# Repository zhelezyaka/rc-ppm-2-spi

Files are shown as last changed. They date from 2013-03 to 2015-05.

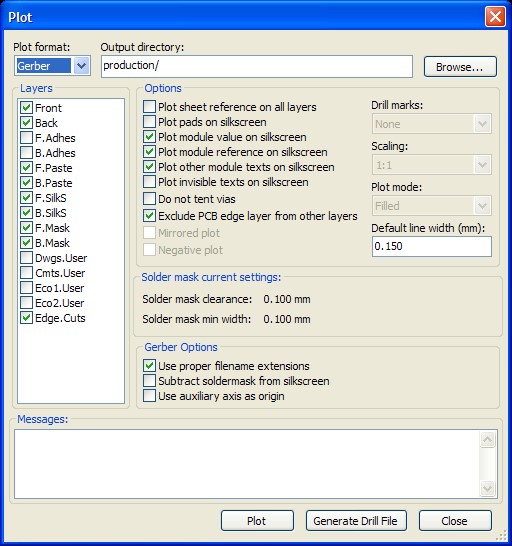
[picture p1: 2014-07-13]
pcb/production/kicad_gerber_settings.jpg

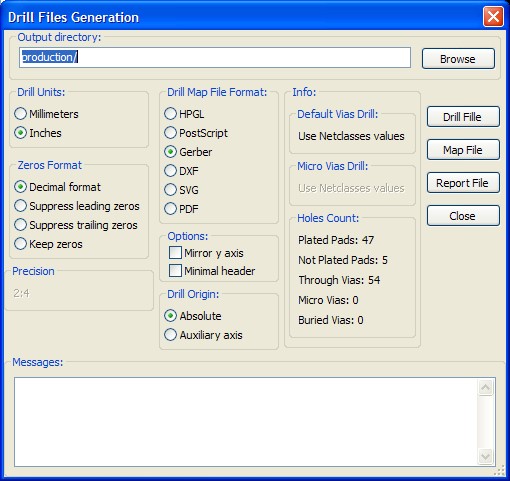
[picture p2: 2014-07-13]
pcb/production/kicad_drill_settings.jpg

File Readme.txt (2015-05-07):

# rc-ppm-2-spi
Automatically exported from:
http://code.google.com/p/rc-ppm-2-spi/

This project aims to provide you with a RC module that will allow you fly models featuring the A7105 transceiver chip 
using your favourite modular transmitter, instead of using the cheap efforts that are normally supplied.

http://rc-ppm-2-spi.googlecode.com/svn/wiki/images/overview/overview_03.jpg

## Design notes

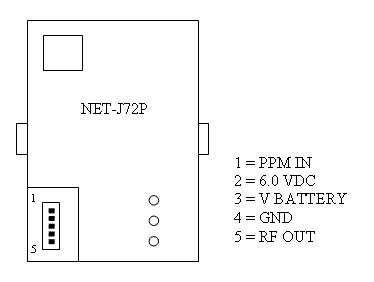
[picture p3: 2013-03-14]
datasheets/JR_module_pinout.gif

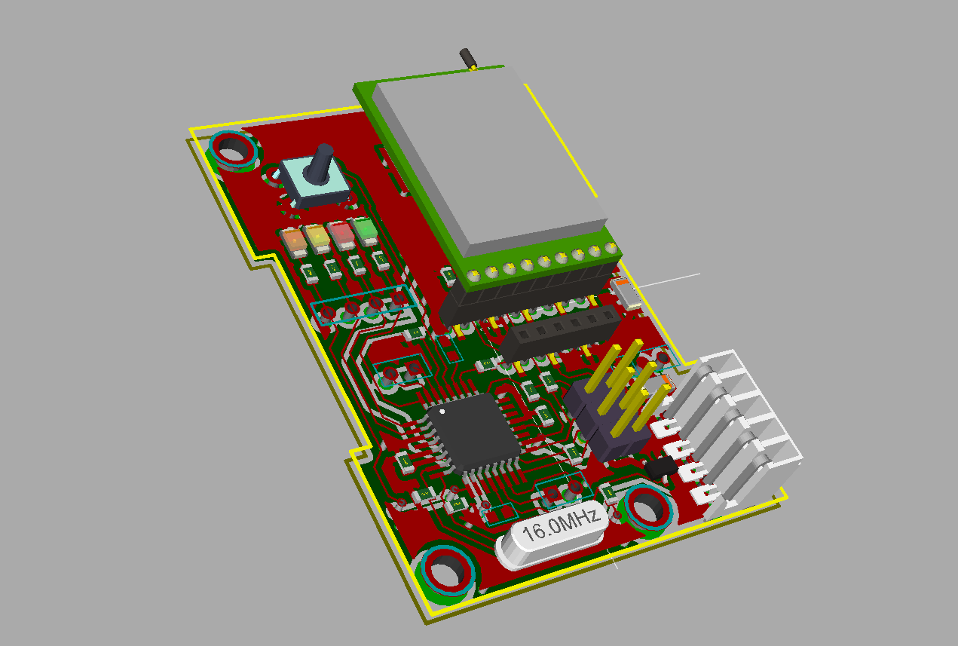
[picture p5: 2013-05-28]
pcb/ppm2spi_ali.png

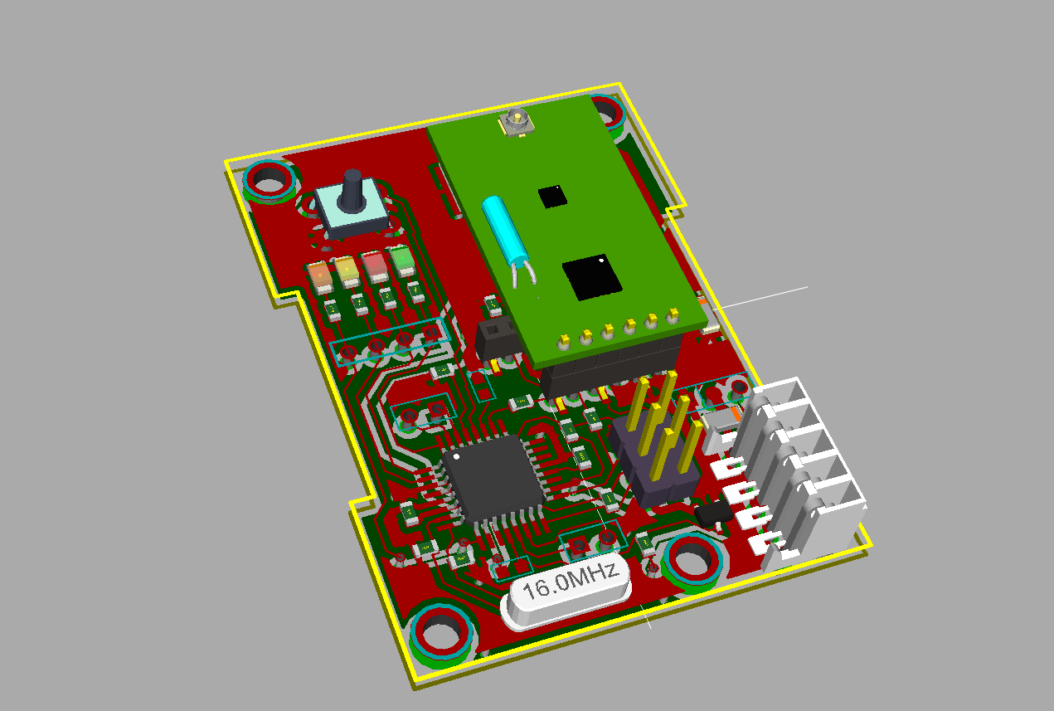
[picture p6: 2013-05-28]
pcb/ppm2spi_jp.png

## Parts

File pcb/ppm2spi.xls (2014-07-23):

Value | Qty | MOQ | Unit Cost | Qty Cost (Inc. VAT) | Designator | Footprint | Manufacturer | Manufactures Part No | Link | Comment | More Comments
18pF | 2 | 100 | £0.006 | £0.72 | C6 C7 | 0603 | Multicomp | MCCA000195 | http://uk.farnell.com/multicomp/mcca000195/cap-ceramic-18pf-50v-c0g-np0-0603/dp/1759056
100nF | 5 | 10 | £0.006 | £0.07 | C1 C4 C5 C9 C10 | 0603 | Multicomp | MC0603B104K250CT | http://uk.farnell.com/multicomp/mc0603b104k250ct/cap-mlcc-x7r-100nf-25v-0603/dp/1759037
10uf 6.3v | 1 | 5 | £0.120 | £0.72 | C8 | 1206 | Vishay Sprague | 293D106X96R3A2TE3 | http://uk.farnell.com/vishay-sprague/293d106x96r3a2te3/capacitor-tantalum-6-3v-10uf/dp/1754143
10uf 16v | 2 | 5 | £0.136 | £0.82 | C2 C3 | 1206 | Kemet | T491A106K016AT | http://uk.farnell.com/kemet/t491a106k016at/capacitor-tant-10uf-16v-10-1206/dp/1457414
Green LED | 1 | 5 | £0.130 | £0.78 | D1 | 0805 | Kingbright | KPHCM-2012CGCK | http://uk.farnell.com/jsp/search/productdetail.jsp?sku=1686075&CMP=i-7395-00001000
Red LED | 1 | 5 | £0.120 | £0.72 | D2 | 0805 | Kingbright | KPHCM-2012SURCK | http://uk.farnell.com/jsp/search/productdetail.jsp?sku=1686067&CMP=i-7395-00001000
Yellow LED | 1 | 5 | £0.120 | £0.72 | D3 | 0805 | Kingbright | KPHCM-2012SYCK | http://uk.farnell.com/jsp/search/productdetail.jsp?sku=1686073&CMP=i-7395-00001000
Orange LED | 1 | 5 | £0.120 | £0.72 | D4 | 0805 | Kingbright | KPHCM-2012SECK | http://uk.farnell.com/jsp/search/productdetail.jsp?sku=1686068&CMP=i-7395-00001000
BAT54S | 1 | 5 | £0.044 | £0.26 | D5 | SOT23 | NXP | BAT54S | http://uk.farnell.com/nxp/bat54s/diode-schoty-dual-30v-0-2a-sot23/dp/1081194
ATMEGA328-AU | 1 | 1 | £2.630 | £3.16 | IC1 | TQFP32 | Atmel | ATMEGA328-AU | http://uk.farnell.com/jsp/search/productdetail.jsp?id=1972086&Ntt=ATMEGA328-A
Molex KK100 4455 5 way | 1 | 5 | £0.620 | £3.72 | P1 | 0.1"x5 | Molex | 38-00-1395 | http://uk.farnell.com/jsp/search/productdetail.jsp?SKU=9732349
0.1" pin header 3 way | 1 | 1 | £1.480 | £1.78 | K1 | 0.1"x3 | FCI | 77311-401-36LF | http://uk.farnell.com/fci/77311-401-36lf/header-pin-tin-36way-1row/dp/1097954 | Optional for alternative PPM input
0.1" pin header 2 way | 1 | NA | NA | NA | P5 | 0.1"x2 | As above | As above | As above | Optional for debugging - PB1 PB2
0.1" pin header 2 way | 1 | NA | NA | NA | P7 | 0.1"x2 | As above | As above | As above | Optional for debugging- Tx Rx
0.1" pin header 4 way | 1 | NA | NA | NA | P6 | 0.1"x4 | As above | As above | As above | Optional for debugging - LED signals
0.1" pin header 3x2 way | 1 | 1 | £2.310 | £2.77 | P3 | 0.1"x3x2 | Harwin | M20-9983646 | http://uk.farnell.com/harwin/m20-9983646/header-2row-36-36way/dp/1022244 | ISP Header
2mm pin socket 6 way | 1 | 1 | £2.170 | £2.60 | P2 | 2mmx6 | Samtec | SMM-110-02-S-S | http://uk.farnell.com/samtec/smm-110-02-s-s/receptacle-2mm-single-10way/dp/1668127 | Cut to length - For use with WL Toys module | Xbee trough hole headers are a cheaper alternative
2mm pin socket 9 way | 1 | NA | NA | NA | P4 | 2mmx9 | As above | As above | As above (http://uk.farnell.com/samtec/smm-109-01-s-s/socket-2-0mm-1x9way/dp/1804773) | Cut to length - For use with AliExpress A7105 500m module | Xbee through hole headers are a cheaper alternative
1K | 8 | 50 | £0.011 | £0.66 | R2 R3 R4 R7 R9 R10 R11 R12 | 0603 | Vishay Draloric | CRCW06031K00FKEA | http://uk.farnell.com/vishay-draloric/crcw06031k00fkea/resistor-0603-1kr-1-0-1w/dp/1469740
2K | 3 | 50 | £0.009 | £0.54 | R1 R5 R6 | 0603 | Panasonic | ERJ3GEYJ202V | http://uk.farnell.com/panasonic/erj3ekf2001v/resistor-2k-0-1w-1/dp/2059343
10K | 1 | 50 | £0.011 | £0.66 | R8 | 0603 | Vishay Draloric | CRCW060310K0FKEA | http://uk.farnell.com/vishay-draloric/crcw060310k0fkea/resistor-10k-0-1w-1-0603-smd/dp/1469748
SW_PUSH | 1 | 1 | £0.130 | £0.16 | SW1 | 6x6mm | Alps | SKHHANA010 | http://uk.farnell.com/alps/skhhana010/switch-tactile-6x6mm-vert-blk/dp/2056810
5v Regulator | 1 | 1 | £0.540 | £0.65 | U1 | SOT89 | Microchip | MCP1703AT-5002E/MB | http://uk.farnell.com/microchip/mcp1703at-5002e-mb/ldo-2-7-16vin-0-25a-5v-2-3sot89/dp/2218577 | Pin order: OUT GND IN
3.3v Regulator | 1 | 1 | £0.720 | £0.86 | U2 | DPAK2 | ST | KF33BDT-TR | http://uk.farnell.com/stmicroelectronics/kf33bdt-tr/ic-v-reg-ldo-3-3v-smd/dp/1467756 | Pin order: IN GND OUT
16Mhz Crystal | 1 | 1 | £0.270 | £0.32 | X1 | HC49 | Raltron | AS-16.000-18 | http://uk.farnell.com/raltron/as-16-000-18/crystal-16m-18pf-cl-hc49-4h/dp/1611761
A7105 RF module | 1 | 1 | £6.008 | £7.21 | Connects to P2 or P4 | NA | NA | NA | http://www.aliexpress.com/item/A7105-Wireless-RF-2-4GHz-Transceiver-Module-3-3V-NRF24L01-SI4432-10dBm-64mA-20mA/619869938.html | Either taken from original Tx or bought from AliExpress
Spektrum module case | 1 | 1 | £12.908 | £15.49 | NA | NA | Spektrum | SPM6817E | http://www.horizonhobby.co.uk/aeroonline/e6spektrum/e6_modules/e6_jr_module/e6_jr.html
Total Cost inc. VAT |  |  |  | £46.11

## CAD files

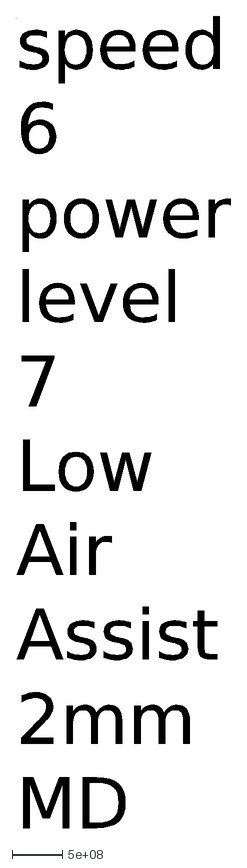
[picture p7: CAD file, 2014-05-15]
diymodulecase/diymodulecase.dxf
speed 6 power level 7 Low Air Assist 2mm MDF

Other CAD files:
diymodulecase/diymodulecase.dwg

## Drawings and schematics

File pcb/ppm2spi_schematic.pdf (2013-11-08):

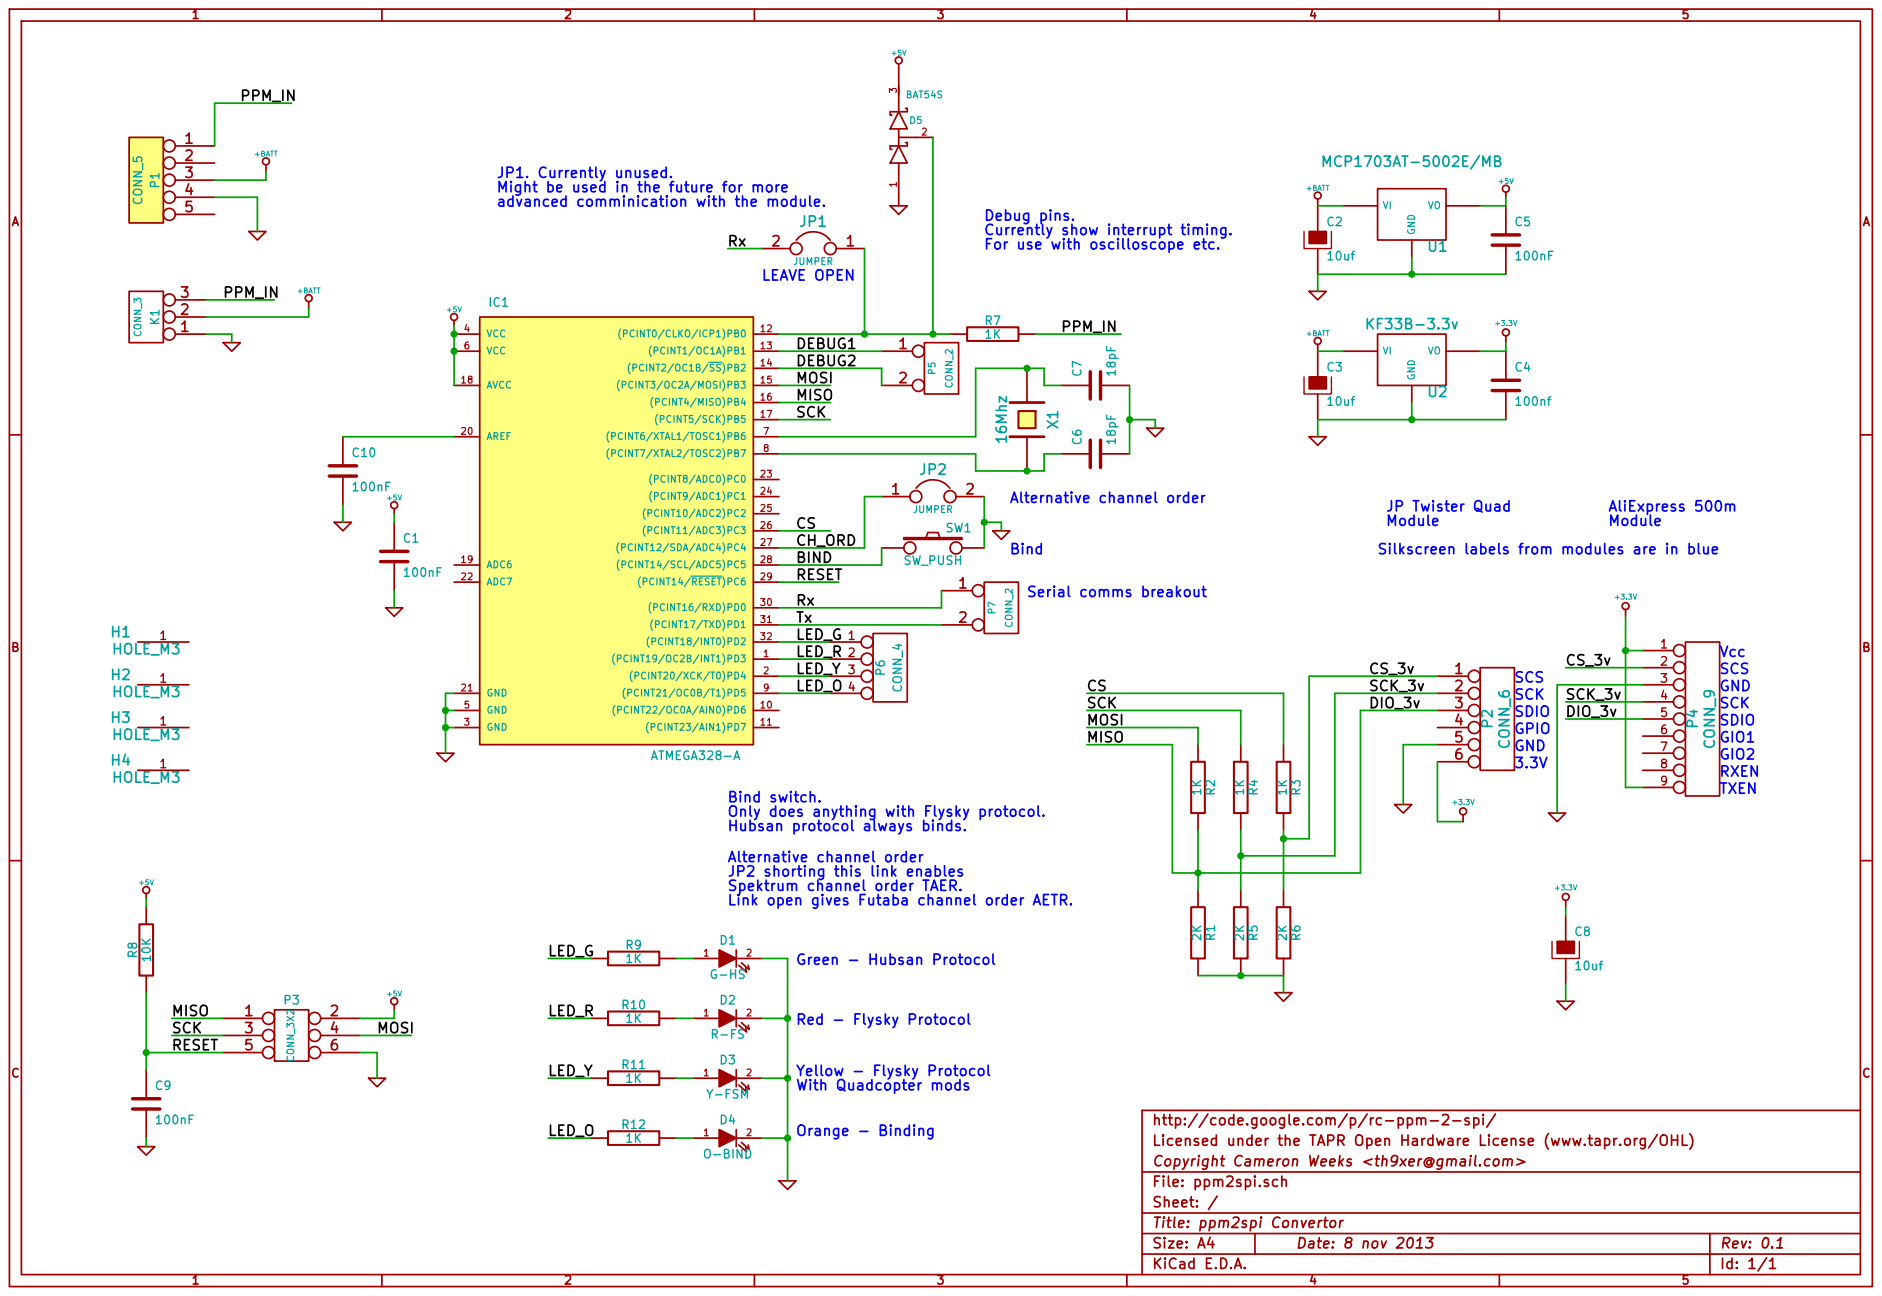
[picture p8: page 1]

JP1. Currently unused.
Might be used in the future for more

Silkscreen labels from modules are in blue Bind switch. Only does anything with Flysky protocol.

Hubsan protocol always binds.

Spektrum channel order TAER.

http://code.google.com/p/rc-ppm-2-spi/
Licensed under the TAPR Open Hardware License (www.tapr.org/OHL)
Copyright Cameron Weeks <th9xer@gmail.com>
File: ppm2spi.sch
Sheet: /
Title: ppm2spi Convertor

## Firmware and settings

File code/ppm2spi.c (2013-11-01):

/*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
 This file is the work of and copyright Cameron Weeks <th9xer@gmail.com>
 http://code.google.com/p/rc-ppm-2-spi/
 
 Thanks to Kilrah for the Spektrum channel order implimentation

 */
 
#include "common.h"
#include <avr/io.h>
#include <util/delay.h>
#include <stdlib.h>
#include <avr/interrupt.h>
#include <avr/pgmspace.h>
#include <avr/eeprom.h>
#include <avr/wdt.h> 

#define NEUTRAL 0

//We have 7 modes and a servo travel of 20000 (+-10000) 
//20000/7 = 2857 
#define MODE_DIVISOR 2858 

// ******************************************************************************************
// ******                        Global Variables                                      ******
// ******************************************************************************************

volatile uint8_t g_servo_count = 0;
volatile uint8_t g_sync_count = 0;
volatile uint16_t g_icr1_previous = 0;
volatile uint8_t g_initializing = 1;
volatile uint8_t g_need_to_sync = 1;
volatile uint16_t g_entropy = 0;
uint8_t proto_mode;
struct Transmitter Transmitter;
struct Model Model;
volatile s16 Channels[NUM_OUT_CHANNELS];
volatile uint8_t g_spektrum_order = 0;

s16 chtemp;
int main (void)
{
int16_t i;
uint8_t j;
uint8_t mcusr_mirror;

//The correct sequence of events to disable the watchdog timer
mcusr_mirror = MCUSR;
MCUSR = 0;
wdt_disable();

Model.num_channels = 8;
Model.tx_power = TXPOWER_100mW ;
g_entropy=0;

PORTB=0;
gpio_clear (DDRB, PPM_IN);  // Input  pin0
gpio_set   (DDRB, DEBUG_1); // Output pin1
gpio_set   (DDRB, DEBUG_2); // Output pin2 (SS output - General purpose output pin)
gpio_set   (DDRB,3);        // MOSI output 
gpio_clear (DDRB,4);        // MISO input
gpio_set   (DDRB,5);        // SCK output

PORTC=0;
gpio_set   (DDRC, SPI_CS);   // Output pin3
gpio_clear (DDRC, CH_ORD);   // Input pin4
gpio_set   (PORTC,CH_ORD);   // Pull up resistor on pin4
gpio_clear (DDRC, BIND_SW);  // Input pin5
gpio_set   (PORTC,BIND_SW);  // Pull up resistor on pin5


PORTD=0;
gpio_clear (DDRD, 0);  // Serial Rx input
gpio_set   (DDRD, 1);  // Serial Tx output
gpio_set   (DDRD, LED_G);  // LED green  pin2
gpio_set   (DDRD, LED_R);  // LED red    pin3
gpio_set   (DDRD, LED_Y);  // LED yellow pin4
gpio_set   (DDRD, LED_O);  // LED orange pin5


/* Bit bang SPI, to delete
// SPI INIT Bidirectional one wire mode, set to output
DATA_BI_OUT();
DATA_BI_LO();
DATA_PD_LOW();
CLK_OUT();
CLK_LO();
CS_OUT();
CS_HI();
*/


// SPI Setup
//No interrupts SPIE=0 , SPI Enable SPE=1, MSB first DORD=0, Master mode MSTR =1
//Clock polarity, idle low CPOL=0, Sample leading edge CPHA=0, fosc/2 SPR1=0 SPR0=0 SPI2X=1
//Thanks Rick for the tip that fosc/2 worked ok !
SPCR = (1<<SPE) | (1<<MSTR) | (1<<SPR0);
SPSR |= (1<<SPI2X);

// Set up for input capture on PD6
// Normal mode, OVF @ TOP (0xFFFF), F_CPU/8, noice cancler on ICP, falling edge trigger
// 2Mhz Tick
TCCR1B = (1<<ICNC1) | (2<<CS10); // falling edge trigger 
//TCCR1B = (1<<ICNC1) | (2<<CS10) | (1<<ICES1); //rising edge trigger

// Enable ICP interrupt
TIMSK1 = (1<<ICIE1); 
// Global interrupt enable
sei();

//Wait until we have received 20 PPM packets.
//Gives tx output time to start.
while (g_sync_count <= 20) ;   

// Disable Input Capture
TCCR1B &= ~(1<<ICNC1);

// Get some much needed entropy for rand()
srand(g_entropy); 

// Check to see if a tx id has been generated before
if (eeprom_read_byte((uint8_t*)0x05) == eeprom_read_byte((uint8_t*)0x06))
	{
	Model.fixed_id = rand() + ((u32)rand() << 16);
	eeprom_write_dword ((uint32_t*)0x00,Model.fixed_id);
	eeprom_write_byte ((uint8_t*)5,0x34); //Just two different numbers to denote a locked in tx id
	eeprom_write_byte ((uint8_t*)6,0xA4);
	}
else
	{
	Model.fixed_id = eeprom_read_dword((uint32_t*)0x00);
	}

// There is a possible bug in the FlySky protocol code (flysky_a7105.c). 
// Thanks Rick for spotting this, you know who you are !
//
// To set the picture:
// to obtain the channel number chanoffset is subtracted from a number in tx_channels[]
// The code in flysky_a7105.c is:
// A7105_WriteData(packet, 21, tx_channels[chanrow][chancol]-chanoffset);
//
// The chanoffset variable which is some number between 0-15 (and as it is solely based 
// on tx id could well be any of these numbers) is going to cause a negative channel 
// number (or wrap around, whatever you want to call it) at some point because the 
// lowest channel number in tx_channels[] is 10.
//
// chanoffset is (bits 4-7 of tx id) and is controllable independently from 
// chanrow (bits 0-3 of tx id) and chancol (rolling 0-15), so this is 
// guaranteed to happen given the right tx id.
//
// Therefore we must constrain bits 4-7 of tx id to 0-9 to be safe

if (((Model.fixed_id & 0xff) / 16) > 9 ) 
	{
	Model.fixed_id &= 0xffffff0f;
	Model.fixed_id |= 0x00000090;
	}

//Channel 8 tells us what mode to be in
chtemp = Channels[7];
for (i=(-10000+MODE_DIVISOR), j=0; i<chtemp; i+=MODE_DIVISOR, j++);

switch (j)
	{
	case 0:
	proto_mode=FLYSKY_STD; 
	gpio_set(PORTD,LED_R);
	break;

	case 1:
	proto_mode=FLYSKY_MOD; 
	gpio_set(PORTD,LED_Y);
	break;

	case 2:
	proto_mode=HUBSAN_STD; 
	gpio_set(PORTD,LED_G);
	break;

	case 3:
	proto_mode=JP_NANOSTIK; 
	gpio_set(PORTD,LED_R);
	gpio_set(PORTD,LED_Y);
	while(1); //Not yet implimented so stop
	break;

	case 4:
	proto_mode=SPARE_PROTO1; 
	gpio_set(PORTD,LED_Y);
	gpio_set(PORTD,LED_G);
	while(1); //Not yet implimented so stop
	break;

	case 5:
	proto_mode=SPARE_PROTO2; 
	gpio_set(PORTD,LED_G);
	gpio_set(PORTD,LED_R);
	while(1); //Not yet implimented so stop
	break;

	case 6:
	proto_mode=SET_ID; 
	gpio_set(PORTD,LED_G);
	gpio_set(PORTD,LED_R);
	gpio_set(PORTD,LED_Y);
	break;
	}

if (proto_mode == SET_ID)
	{
	while (1)
		{
		if (!BIND_SW_READ()) break;
		_delay_ms(300);
		gpio_clear(PORTD,LED_G);
		gpio_clear(PORTD,LED_R);
		gpio_clear(PORTD,LED_Y);
		if (!BIND_SW_READ()) break;
		_delay_ms(300);
		gpio_set(PORTD,LED_G);
		gpio_set(PORTD,LED_R);
		gpio_set(PORTD,LED_Y);
		}
	gpio_set(PORTD,LED_G);
	gpio_set(PORTD,LED_R);
	gpio_set(PORTD,LED_Y);
	while (!BIND_SW_READ()); //Wait for button release
	eeprom_write_byte ((uint8_t*)5,0xFF); //Make sure a new tx id is picked at boot up
	eeprom_write_byte ((uint8_t*)6,0xFF); //Make sure a new tx id is picked at boot up
	while (!eeprom_is_ready()) {} //Make sure EEPROM write finishes
	//cli(); // disable interrupts
  	wdt_enable(WDTO_250MS); // enable watchdog
  	while(1); // wait for watchdog to reset processor 
	}


if (proto_mode == HUBSAN_STD) 
	{HUBSAN_Cmds(PROTOCMD_BIND); gpio_set(PORTD,LED_O);}

if (proto_mode == FLYSKY_MOD || proto_mode == FLYSKY_STD)
	{
	if (!BIND_SW_READ())
		{FLYSKY_Cmds(PROTOCMD_BIND);  gpio_set(PORTD,LED_O);}
	else
		{FLYSKY_Cmds(PROTOCMD_INIT);}
	}
	
if(!CH_ORD_READ()) g_spektrum_order = 1;
while (g_initializing) ; //wait until initialization has occured before re-enabling the PPM interrupt
gpio_clear(PORTD,LED_O);

// Enable Input Capture
g_need_to_sync = 1;
g_icr1_previous = ICR1;
TCCR1B |= (1<<ICNC1);

while (1) ;

}


// ******************************************************************************************
// ******                              Interrupt Routine                               ******
// ******************************************************************************************

ISR(TIMER1_CAPT_vect)
{
//each timer tick is half a microsecond
gpio_set(PORTB, DEBUG_1); //High
static uint16_t icr1_current; //static for debug
static int16_t icr1_diff;     //static for debug
int32_t tempch;

if (g_entropy==0) {g_entropy = TCNT1;}

icr1_current=ICR1; 
icr1_diff = icr1_current - g_icr1_previous;
g_icr1_previous = icr1_current;

if (g_servo_count < NUM_OUT_CHANNELS)
	{
	
	// > 3.0ms pulse seen as a frame sync
	if (icr1_diff > 6000)
   		{
   		g_servo_count=0;
   		g_need_to_sync = 0;
   		g_sync_count++;
   		}

	// Pulse within limits and we don't need to sync.	
	else if (!g_need_to_sync)
   		{
   		//1500us is servo centre pulse width
   		//2000L is CHAN_MAX_VALUE / 500us (max deviation from 1500us) * 100 (scaling)
   		//100L undoes the scaling
   		icr1_diff>>=1;
   		if (icr1_diff > 2000) icr1_diff=2000; // Range limiting
   		if (icr1_diff < 1000) icr1_diff=1000; // Range limiting
   		tempch = (int32_t)( ((icr1_diff - 1500L) * 2000L) /100L) ;
			
    	if(g_spektrum_order) // TAER order
			{
    		switch(g_servo_count)
				{
    			case 0:
    				Channels[2] = tempch;
    				break;
   				case 1:
    				Channels[0] = tempch;
    				break;
    			case 2:
    				Channels[1] = tempch;
    				break;
    			default:
					Channels[g_servo_count] = tempch;
				}
			}	
			
		else {Channels[g_servo_count] = tempch;}  //AETR order
				
   		g_servo_count++;
   		}
	}
else
	{
	g_servo_count=0;
   	g_need_to_sync = 0;
	}

gpio_clear(PORTB, DEBUG_1); //Low
}

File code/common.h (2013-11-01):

/*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
 This file is based on work by PhracturedBlue (real name and email ?)
 It can be found here:
 https://bitbucket.org/PhracturedBlue/deviation/src
 
 Alterations by Cameron Weeks <th9xer@gmail.com>
 http://code.google.com/p/rc-ppm-2-spi/
 */
 
#include <stdint.h>
#include <avr/io.h>

typedef int8_t s8;
typedef int16_t s16;
typedef int32_t s32;
typedef uint8_t u8;
typedef uint16_t u16;
typedef uint32_t u32;
typedef uint64_t u64;

#include "iface_a7105.h"

enum TxPower {
    TXPOWER_100uW,
    TXPOWER_300uW,
    TXPOWER_1mW,
    TXPOWER_3mW,
    TXPOWER_10mW,
    TXPOWER_30mW,
    TXPOWER_100mW,
    TXPOWER_150mW,
    TXPOWER_LAST,
};

enum ProtoCmds {
    PROTOCMD_INIT,
    PROTOCMD_DEINIT,
    PROTOCMD_BIND,
    PROTOCMD_CHECK_AUTOBIND,
    PROTOCMD_NUMCHAN,
    PROTOCMD_DEFAULT_NUMCHAN,
    PROTOCMD_CURRENT_ID,
    PROTOCMD_SET_TXPOWER,
    PROTOCMD_GETOPTIONS,
    PROTOCMD_SETOPTIONS,
    PROTOCMD_TELEMETRYSTATE,
};

enum proto_mode {
    FLYSKY_STD,
    FLYSKY_MOD,
    HUBSAN_STD,
	JP_NANOSTIK,
	SPARE_PROTO1,
	SPARE_PROTO2,
	SET_ID
};

struct Model {
    u8 num_channels;
    u32 fixed_id;
    enum TxPower tx_power;
};
extern struct Model Model;

extern volatile uint8_t g_initializing;

extern uint8_t proto_mode;

struct Transmitter {
    u8 dummy;
};
extern struct Transmitter Transmitter;
extern const void *FLYSKY_Cmds(enum ProtoCmds cmd);
extern const void *HUBSAN_Cmds(enum ProtoCmds cmd);

#define NULL ((void *)0)

#define NUM_OUT_CHANNELS 16

//MAX = 10000
//MIN = -10000
#define CHAN_MULTIPLIER 100
#define CHAN_MAX_VALUE (100 * CHAN_MULTIPLIER)
#define CHAN_MIN_VALUE (-100 * CHAN_MULTIPLIER)
extern volatile s16 Channels[NUM_OUT_CHANNELS];

#define BIND_SW_READ() 	(PINC & (1<<BIND_SW))
#define CH_ORD_READ()   (PINC & (1<<CH_ORD))

#define SPI2 2

#define gpio_set(sfr,bit) (sfr) |=   1<<(bit)
#define gpio_clear(sfr,bit) (sfr) &= ~(1<<(bit))

//Port C
#define SPI_CS			3
#define CH_ORD          4
#define	BIND_SW			5

//Port B
#define PPM_IN			0
#define DEBUG_1		    1
#define DEBUG_2     	2

#define CS_HI() 		gpio_set(PORTC, SPI_CS)
#define CS_LO() 		gpio_clear(PORTC, SPI_CS) 

//Port D
#define LED_G 2  // LED green
#define LED_R 3  // LED red
#define LED_Y 4  // LED yellow
#define LED_O 5  // LED orange


/* Bit bang SPI, to delete
#define SPI_PORT	    PORTC
#define SPI_DDR         DDRC
#define SPI_PIN		    PINC

#define CS_OUT()    	gpio_set(SPI_DDR, SPI_CS)
#define SPI_DIO_PD		0
#define SPI_DIO			1
#define SPI_CLK			2
#define SPI_DO      	4

#define CLK_HI() 		gpio_set(SPI_PORT, SPI_CLK) 
#define CLK_LO() 		gpio_clear(SPI_PORT, SPI_CLK)
#define CLK_OUT()   	gpio_set(SPI_DDR,SPI_CLK)

#define DATA_BI_HI() 	gpio_set(SPI_PORT, SPI_DIO) 
#define DATA_BI_LO() 	gpio_clear(SPI_PORT, SPI_DIO)
#define DATA_BI_OUT()  	gpio_set(SPI_DDR, SPI_DIO)
#define DATA_BI_IN()	gpio_clear(SPI_DDR, SPI_DIO)
#define DATA_BI_READ() 	(SPI_PIN & (1<<SPI_DIO))

#define DATA_PD_FLOAT() gpio_clear(SPI_PORT, SPI_DIO_PD); gpio_clear(SPI_DDR, SPI_DIO_PD)
#define DATA_PD_LOW()	gpio_clear(SPI_PORT, SPI_DIO_PD); gpio_set(SPI_DDR, SPI_DIO_PD)

#define DATA_DO_HI()	gpio_set(SPI_PORT, SPI_DO)
#define DATA_DO_LO()	gpio_clear(SPI_PORT, SPI_DO)
#define DATA_DO_OUT()	gpio_set(SPI_DDR, SPI_DO)
*/

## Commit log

2013-03-14 First code revision, just a clone of the working files on my PC
    [ppm2spi.brd, ppm2spi.sch, spi.csv]
2013-03-14 Update to perl spi parser files
    [nanostick_spi.csv, nanostick_spi_frag.csv]
2013-03-14 Hardware changes to allow a serial input as well as PPM
    [ppm2spi.brd, ppm2spi.sch]
2013-03-14 Forgot to break out the debug pins
    [ppm2spi.brd, ppm2spi.sch]
2013-03-24 3D model rename, so I can add some new ones.
    [ppm2spi.brd]
2013-03-24 Addition of models and footprints
2013-04-02 Inclusion of HUBSAN and FLYSKY hex files, previous hex was FLYSKY only. 3D model updates. PCB size change.
    [ppm2spi.brd]
2013-04-24 Fix to the Hubsan protocol. See here http://www.deviationtx.com/forum/6-general-discussions/1425-help-hubsan-x4?start=20#7578 for the origin of the fix. This code still uses software SPI, but next ve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
2013-05-05 Update to hardware SPI, schematic also changed. PCB needs redoing. Notes added to schematic to make it easier to understand.
    [ppm2spi.sch]
2013-05-06 More cleaning up. Also combined all protocols into one hex.
    At power up channel 8 is scanned:
    If it is LOW (1000us +10us) normal Flysky modulation is used and the RED LED is lit.
    If channel 8 is NEUTRAL (1500us +-10us) Flysky modulation with quadcopter mods is used and the YELLOW LED is lit. With these mods enabled channels 5,6,and 7 take on extra rolls, LEDs, flips, camera, etc.
    If channel 8 is high (2000us -10us) Hubsan modulation is used and the GREEN LED is lit.
    Changing channel 8 after power up does not alter the modulation.
    THIS IS ALL UNTESTED ! I'll debug it later today, hopefully it won't need it.
    [common.h, flysky_a7105.c, ppm2spi.c]
2013-05-06 It works... but be careful the various mods on the Flysky protocol can cause unexpected motor starts if you get the wrong one. Ask me how I found out :) see flysky_a7105.c line 172 for more details. 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
    Also added another LED to show when binding is taking place and finished.
    Next the PCB layout.
    [ppm2spi.sch]
2013-05-06 PCB updates, and code cleaning
    [ppm2spi.brd]
2013-05-06 PCB update. Needs silkscreen labels sorting.
    [ppm2spi.brd, ppm2spi.sch]
2013-05-06 Closer with the PCB. Last step a bigger 3.3v reg.
    [ppm2spi.brd, ppm2spi.sch]
2013-05-06 Bigger 3.3v reg. Think that's it done !
    [ppm2spi.brd, ppm2spi.sch]
2013-05-06 Some GND Vias
    [ppm2spi.brd]
2013-05-07 More PCB updates and some feature creep.
    [ppm2spi.brd, ppm2spi.sch]
2013-05-25 Finally the new module connector. Still needs work.
    [ppm2spi.brd]
2013-05-26 Final mods for new connector. PCB now done (I hope).
    [ppm2spi.brd, ppm2spi.sch]
2013-05-26 Board size tweak, narrowing of the waist. Also thought of one more addition, a BAT54 on the PPM input for protection. That will be the next commit.
    [ppm2spi.brd]
2013-05-27 Final PCB update to include BAT54S protection diode on PPM input.
    [ppm2spi.brd, ppm2spi.sch]
2013-05-27 Toying with the idea of up-ing the 5v reg so have added another footprint. Just in case Hman545 (http://openrcforums.com/forum/viewtopic.php?f=5&t=2672&start=120#p51188) hasn't duffed his processor. 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
    [ppm2spi-B_Mask.gbs, ppm2spi-B_Paste.gbp, ppm2spi-B_SilkS.gbo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]
2013-05-28 Upgraded the 5v reg. The previous post looks like it was nothing to do with the 5v reg but I upgraded it anyway.
    [ppm2spi.brd, ppm2spi.sch]
2013-05-28 LED colour mix up corrected. Orange was right, the rest not so.
    [ppm2spi.brd, ppm2spi.sch]
2013-05-28 Comments on schematic updated, and setup code for channel order pin (does nothing currently).
    [ppm2spi.sch]
2013-06-11 Gerbers - PCBs ordered
    [ppm2spi-B_Mask.gbs, ppm2spi-B_Paste.gbp, ppm2spi-B_SilkS.gbo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]
2013-07-05 BOM and neatening of the silkscreen. BOM only has links for the UK at the mo.
    Other points: Weakness in Flysky protocol to be addressed, tx_id needs to be changed from a fixed id, crystal outline too big.
    [ppm2spi.brd, ppm2spi.xls]
2013-07-08 BOM update
    [ppm2spi.xls]
2013-07-09 Rather large PCB error, main module connector was mirrored. Not amused with myself, first batch of PCBs are scrap, not even much use for making control horns. On the up side the rest of the layout se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
    [ppm2spi.brd, ppm2spi.sch]
2013-07-09 Bind button logic reversed. Now how didn't I notice that before !
    [ppm2spi.c]
2013-07-09 Fixed a potential bug in the Flysky protocol, thanks to Rick to the tip off. Also gave the module the ability to randomly create it's ID at very first switch on. Up to now every module had the same I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
    [ppm2spi.c]
2013-07-10 Big changes !! We now have 7 modes the module can be in. The first three are the ones we used to have HUBSAN, FLYSKY_STD, and FLYSKY_MOD, we then have 3 spare slots, and the last mode allows you to c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
2013-07-13 BOM update to include AliExpress A7015 module and Spektrum module case.
    [ppm2spi.xls]
2013-11-01 Updates for xtal spacing on PCB. Addition of Kilrah's Spektrum channel order code, thanks ! Addition of some pictures for Wiki
    [ppm2spi.brd, ppm2spi.xls]
2013-11-01 Speed up of SPI frequency.
2013-11-01 Update of schematic comments to reflect new Spektrum channel order option. Also MOSI is now floating during read in's. This makes for nicer treatment of the A7105.
    [ppm2spi.sch]
2013-11-01 On second thoughts not keen on the under pulse check implementation. One bad pulse can cause you to loose a full frame of data, reverted to last code.
    [ppm2spi.c]
2013-11-08 Updated comments on schematic
    [ppm2spi.sch]
2013-11-08 Changed 5v reg to a more common footprint, changed BOM to suit Updated schematic pdf Ready for the 2nd PCB batch I think.
    [ppm2spi.brd, ppm2spi.sch, ppm2spi.xls]
2013-11-08 Spotted a potential antenna on the GND pour, removed. Old gerber file clear out.
    [ppm2spi-B_Mask.gbs, ppm2spi-B_Paste.gbp, ppm2spi-B_SilkS.gbo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]
2013-11-08 Another GND pour issue
    [ppm2spi.brd]
2013-11-09 More GND pour tweaks
    [ppm2spi.brd]
2013-11-09 More tweaks. Think that's it.
    [ppm2spi.brd]
2013-11-10 Gerber files. LED and anti-flip channels implemented on Hubsan protocol (thanks goebish).
    [ppm2spi.brd]
2014-05-15 Files to explain the new DiyModuleCase.
    [diymodulecase.dwg, diymodulecase.dxf]
2014-05-30 100nf caps discontinued. Thanks Charles !
    [ppm2spi.xls]
2014-07-13 A few silkscreen changes
    [ppm2spi.brd]
2014-07-13 Screengrabs of the gerber and drill settings. Just in case I loose them.
2014-07-23 BOM correction - one of the 10uF 6.3v caps should have been 16v.
    [ppm2spi.xls]

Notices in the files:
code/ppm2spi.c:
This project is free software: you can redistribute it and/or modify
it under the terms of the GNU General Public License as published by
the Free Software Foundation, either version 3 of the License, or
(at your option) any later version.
